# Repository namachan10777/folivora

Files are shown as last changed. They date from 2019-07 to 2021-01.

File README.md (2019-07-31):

# Folivora




Integrated ergonomics input device.

# Dependencies
 * KiCAD
 * OCaml
 * OpenSCAD

# License
MIT License

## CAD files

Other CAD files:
inventor/baseframe.ipt

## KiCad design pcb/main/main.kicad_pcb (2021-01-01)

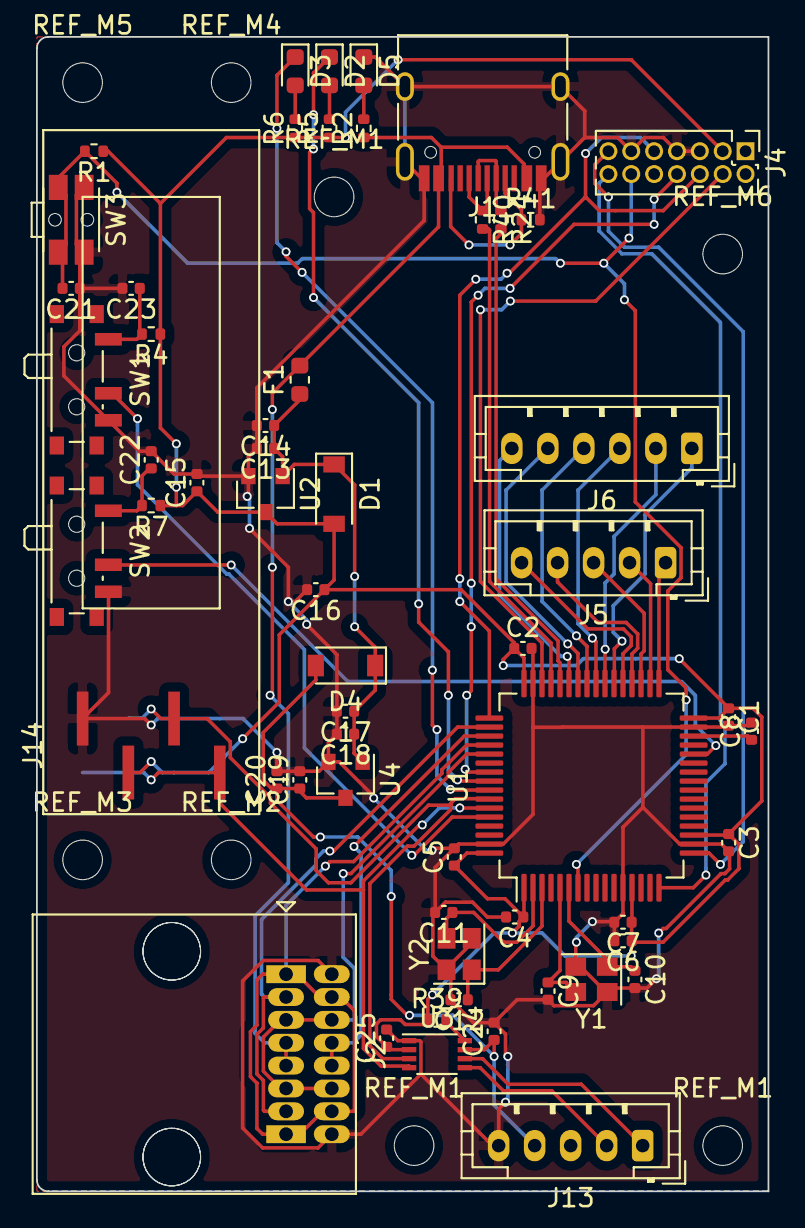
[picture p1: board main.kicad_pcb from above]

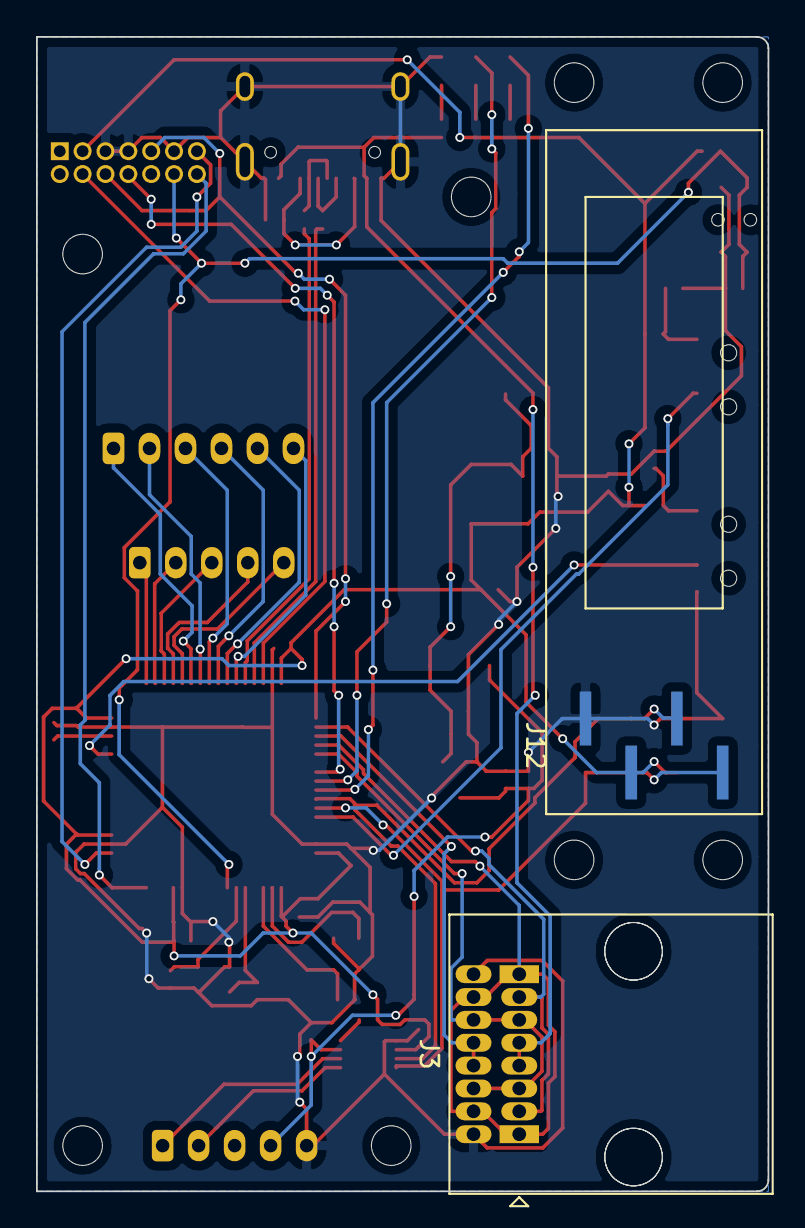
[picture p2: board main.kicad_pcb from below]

Board: 2 copper layers, 40.6 x 64.1 mm, 67 parts (2 on the bottom side), 50 nets.

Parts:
C1, C2, C3, C4, C5, C14, C15, C18, C19, C21, C22, C23, C24, C25: 0.1uF; C_0402_1005Metric
C6, C13, C16, C17, C20: 1uF; C_0402_1005Metric
C7: 10nF; C_0402_1005Metric
C8: 4.7uF; C_0402_1005Metric
C9, C10, C11, C12: C; C_0402_1005Metric
D1, D4: SBD; D_SOD-123
D2: Error; LED_0603_1608Metric
D3: Status; LED_0603_1608Metric
D5: LED_USB; LED_0603_1608Metric
F1: Polyfuse; Fuse_0603_1608Metric
J1: USB_C_Receptacle_USB2.0; USB_C_Receptacle_HRO_TYPE-C-31-M-12
J2, J3: RJ45; RJ45_rev
J4: STLink; PinHeader_2x07_P1.27mm_Vertical
J5: ROW; JST_PH_B5B-PH-K_1x05_P2.00mm_Vertical
J6: COL; JST_PH_B6B-PH-K_1x06_P2.00mm_Vertical
J12, J14: OLED
J13: trackball; JST_PH_B5B-PH-K_1x05_P2.00mm_Vertical
R1, R2, R4, R5, R6, R7, R39: R; R_0402_1005Metric
R24, R40: 10; R_0402_1005Metric
R41: 5.1k; R_0402_1005Metric
REF_M1, REF_M1#2, REF_M1#3, REF_M2, REF_M3, REF_M4, REF_M5, REF_M6: MountingHole_2.2mm_M2
SW1, SW2: SW_SPDT; SW_SPDT_PCM12
SW3: RESET; SW_SPST_EVQP7C
U1: STM32F401RETx; LQFP-64_10x10mm_P0.5mm
U2: NATLINEAR XT1861B332MR-G; SOT-23
U3: PCA9306DC1; VSSOP-8_2.3x2mm_P0.5mm
U4: HT7727; SOT-23
Y1: Crystal_8MHz; Crystal_SMD_2520-4Pin_2.5x2.0mm
Y2: Crystal_32.768MHz; Crystal_SMD_2520-4Pin_2.5x2.0mm

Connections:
+2V8: C19.1, C20.1, C24.1, D4.2, J13.4, U3.7, U4.3
+3V3: C1.1, C2.1, C3.1, C4.1, C5.1, C6.1, C7.1, C15.1, C16.1, C25.1, D1.2, J4.3, J12.2, J14.2, R1.1, R4.1, R5.1, R6.1, R7.1, R39.1, U1.1, U1.13, U1.19, U1.32, U1.48, U1.64, U2.3, U3.2
/BOOT0: SW1.2, U1.60
/BOOT1: SW2.2, U1.28
/COL1: J6.1, U1.38
/COL2: J6.2, U1.39
/COL3: J6.3, U1.40
/COL4: J6.4, U1.41
/COL5: J6.5, U1.42
/COL6: J6.6, U1.43
/D2+: J1.A7, J1.B7, R24.1
/D2-: J1.A6, J1.B6, R40.1
/D+: R24.2, U1.44
/D-: R40.2, U1.45
/LED_ERROR: D2.1, U1.56
/LED_STATUS: D3.1, U1.57
/MISO: J2.1, J2.2, J3.1, J3.2, U1.52
/MOSI: J2.3, J2.6, J3.3, J3.6, U1.53
/NRST: C21.2, J4.12, R1.2, SW3.2, U1.7
/ROW1: J5.1, U1.33
/ROW2: J5.2, U1.34
/ROW3: J5.3, U1.35
/ROW4: J5.4, U1.36
/ROW5: J5.5, U1.37
/RX: J4.13, U1.17
/SCL: J12.3, J14.3, U1.58, U3.3
/SCLK: J2.4, J3.4, U1.51
/SDA: J12.4, J14.4, U1.59, U3.4
/SS: J2.7, J3.7, U1.50
/SWCLK: J4.6, J4.9, U1.49
/SWDIO: J4.4, U1.46
/SWO: J4.8, U1.55
/TX: J4.14, U1.16
/XTAL1A: C9.1, U1.5, Y1.3
/XTAL1B: C10.1, U1.6, Y1.1
/XTAL2A: C11.1, U1.2, Y2.3
/XTAL2B: C12.1, U1.3, Y2.1
GND: C1.2, C2.2, C3.2, C4.2, C5.2, C6.2, C7.2, C8.2, C9.2, C10.2, C11.2, C12.2, C13.2, C14.2, C15.2, C16.2, C17.2, C18.2, C19.2, C20.2, C21.1, C22.2, C23.2, C24.2, C25.2, D5.1, J1.A1, J1.A12, J1.B1, J1.B12, J1.S1, J2.8, J3.8, J4.5, J4.7, J4.11, J12.1, J13.5, J14.1, R41.2, SW1.3, SW2.3, SW3.1, U1.12, U1.18, U1.31, U1.47, U1.63, U2.2, U3.1, U4.2, Y1.2, Y1.4, Y2.2, Y2.4
unnamed: C8.1, U1.30
unnamed: C13.1, C14.1, C17.1, C18.1, D1.1, D4.1, F1.1, U2.1, U4.1
unnamed: C22.1, R7.2, SW2.1
unnamed: C23.1, R4.2, SW1.1
unnamed: D2.2, R5.2
unnamed: D3.2, R6.2
unnamed: D5.2, R2.2
unnamed: J1.A5, J1.B5, R41.1
unnamed: J13.1, U3.6
unnamed: J13.2, U3.5
unnamed: R39.2, U3.8
VBUS: F1.2, J1.A4, J1.A9, J1.B4, J1.B9, J2.5, J3.5, R2.1

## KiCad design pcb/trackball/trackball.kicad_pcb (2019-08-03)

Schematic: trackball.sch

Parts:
C1, C3, C4, C5: 0.1uF; C_0603_1608Metric
J1: 5V; TestPoint_THTPad_D1.0mm_Drill0.5mm
J2: UP; TestPoint_THTPad_D1.0mm_Drill0.5mm
J3: R; TestPoint_THTPad_D1.0mm_Drill0.5mm
J4: D; TestPoint_THTPad_D1.0mm_Drill0.5mm
J5: L; TestPoint_THTPad_D1.0mm_Drill0.5mm
J7: GND; TestPoint_THTPad_D1.0mm_Drill0.5mm
R6, R7, R8, R9: 10k; R_0603_1608Metric
U1, U2, U3, U4: AN48841B; SMINI_5DE

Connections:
+5V: C1.1, C3.1, C4.1, C5.1, J1.1, R6.1, R7.1, R8.1, R9.1, U1.4 (Vcc), U2.4 (Vcc), U3.4 (Vcc), U4.4 (Vcc)
/DOWN: J4.1, R8.2, U3.5 (OUT)
/LEFT: J5.1, R9.2, U4.5 (OUT)
/RIGHT: J3.1, R7.2, U2.5 (OUT)
/UP: J2.1, R6.2, U1.5 (OUT)
GND: C1.2, C3.2, C4.2, C5.2, J7.1, U1.2 (GND), U2.2 (GND), U3.2 (GND), U4.2 (GND)

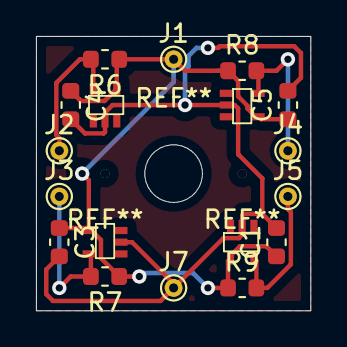
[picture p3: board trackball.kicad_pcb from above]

Board: 2 copper layers, 15.2 x 15.2 mm, 18 parts (0 on the bottom side), 6 nets.

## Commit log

2018-06-03 add mechanical design
    [Part6.ipt, ThumbPlate.ipt, baseframe.ipt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]
2018-07-06 update mechanical design
    [ball.ipt, ballcover.ipt, bearing.ipt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]
2018-07-20 設計の整理
    [Part6.ipt, ThumbPlate.ipt, ball.ipt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]
2018-07-21 左手側を追加
    [baseframe_left.ipt, folivora.iam, keyplate2.ipt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]
2018-07-21 どうにかしてセンサー設置空間を確保
    妥協と諦め
    [folivora.iam, trackball-cover.ipt, trackball_l.ipt]
2018-07-22 インターフェース設置用の穴を開けた
    [folivora.iam, palmrest-plate.ipt]
2018-07-22 add optsensor pcb
    [optsensor.kicad_pcb, optsensor.sch, trackball-base.dxf]
2018-07-27 左右対称なデザイン
    [baseframe_left.ipt, bearingcover.ipt, folivora.iam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]
2018-07-27 add drawings
    [baseframe.dxf, bearingcover.dxf, keyL.dxf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]
2018-07-28 add part of catting pattern
    [baseframe.dxf, bearingcover.dxf, keyL.dxf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]
2018-07-28 improve palmrest
    [folivora.iam, palmrest-plate.ipt, palmrest.ipt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]
2018-07-29 extend key
    [folivora.iam, keyL_extended.ipt, keyplate2.ipt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]
2018-07-29 down palmrest
    [folivora.iam, palmrest.ipt, palmrest_left.ipt]
2018-07-30 secure space for main pcb
    [main.kicad_pcb, palmrest-plate.dxf, palmrest-plate.ipt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]
2018-07-30 palmrestとキーの間に空間を設ける
    [baseframe_left.ipt, folivora.iam, palmrest.ipt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]
2018-08-10 revision design
    生産性の向上
    [baseframe_left.ipt, folivora.iam, keyL.ipt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]
2018-09-18 add main schematic
    [main.sch]
2018-09-18 fix directory structure
    [main.kicad_pcb, main.sch]
2018-09-18 remove regacy files
    [optsensor.kicad_pcb, optsensor.sch]
2018-09-18 determine circuit constant
    [main.sch]
2018-09-18 add XH6 to connect trackball
    [main.sch]
2018-09-18 impl main pcb
    [main.kicad_pcb, main.sch]
2018-09-22 fix main pcb
    [main.kicad_pcb, main.sch]
2018-09-22 update optsensor schematic
    [optsensor.sch]
2018-10-31 3d: add base
    [top.scad]
2018-11-01 add trackball anhorage
    [top.scad]
2018-11-04 improve naming of 3d/top.scad
    [top.scad]
2018-11-04 add bearing_cover
    [bearing_cover.scad]
2018-11-04 add ball_cover
    [ball_const.scad, ball_cover.scad, bearing_cover.scad]
2018-11-05 add screw hole to ball cover
    [ball_cover.scad]
2018-11-05 add bearing_base.scad
    [ball_const.scad, ball_cover.scad, bearing_base.scad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]
2018-11-05 fix warning of top.scad
    [top.scad]
2018-11-05 fix inside out
    [top.scad]
2018-11-05 add bearing_base to top.scad
    [bearing_base.scad, top.scad]
2018-11-05 add anchorage to trackball bridge
    [top.scad]
2018-11-10 fix trackball design
    [ball_const.scad, ball_cover.scad, bearing_base.scad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]
2018-11-22 reduce bearing module size
    [ball_const.scad, ball_cover.scad, bearing_base.scad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]
2018-11-30 Hello clojure!
    [ball_const.scad, ball_cover.scad, bearing_base.scad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]
2018-12-08 impl joint
2019-01-13 impl padding for key joint
2019-01-30 impl joint padding
2019-02-09 3d: add joint sidewall
2019-02-16 mechanical design
    [col4.kicad_pcb, col4.sch, main.kicad_pcb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]
2019-02-20 add bearing_hole
2019-02-20 impl bearing_holes
2019-02-20 refactor track.ml
2019-02-21 fix Track.foundation
2019-02-23 main pcb: fill
    [main.kicad_pcb]
2019-02-23 add pcb opt
    [opt.kicad_pcb, opt.sch]
2019-02-23 add bearinghdge hollowing
2019-02-23 add screw_holes
2019-02-23 impl bearing_cover
2019-02-26 下から球が抜けるように
2019-02-28 Track: for FDM
2019-03-04 最初の方
2019-03-09 add zip-pcb-files.sh
2019-03-10 for Φ2.5 axis
2019-03-10 actually, I use Φ3
2019-03-11 hollow for screw head
2019-03-11 for Φ12.5 sphere
2019-03-12 fix bearing cover tilt
2019-03-13 revise main pcb
    [main.kicad_pcb, main.sch]
2019-03-17 revise row
    [col4.kicad_pcb, col4.sch, row.kicad_pcb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]
2019-03-18 complete sch
    [main.sch]
2019-03-18 arrange parts
    [main.kicad_pcb]
2019-03-18 use STM32F103C8T6 directly
    [main.kicad_pcb, main.sch]
2019-03-19 keyboard pcb
    [main.kicad_pcb, main.sch]
2019-03-19 add main-trackball
    [main.kicad_pcb, main.sch]
2019-03-20 fix design
    [main.kicad_pcb, main.sch, row.kicad_pcb]
2019-03-22 for Φ25
2019-03-22 slanting cut
2019-03-27 temporarily assembled wall
2019-03-28 screw holes for keymodule
2019-03-29 X axis values are determined by inch
    This is so humiliating...
2019-03-29 infinit probability
    [breakout.kicad_pcb, breakout.sch, row.kicad_pcb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]
2019-04-08 rename track -> thumb
2019-04-12 joint thumb and pad
2019-04-14 add wire passage
2019-04-16 impl plate
2019-07-22 add blackberry trackball parts
    [trackball.kicad_pcb, trackball.sch]
2019-07-23 complete trackball breakout
    [trackball.kicad_pcb, trackball.sch]
2019-07-27 trackball breakout
    [trackball.kicad_pcb, trackball.sch]
2019-07-29 add screw_mount
2019-07-30 rm pcbs
    [breakout.kicad_pcb, breakout.sch, main.kicad_pcb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]
2019-07-30 add plate
2019-07-31 improve circuit board mount point
2019-07-31 manual scaling circuit board.
2019-08-03 change BlackPill footprint non-reversible
2019-08-03 optimized electrical board space
2019-08-03 complete pcb design
    [main.kicad_pcb, main.sch]
2019-08-03 resize main pcb
    [main.kicad_pcb]
2019-08-03 hollow cable tunnel
2019-08-03 production pcb
    [main.kicad_pcb, trackball.kicad_pcb]
2019-08-03 add Micro_hole footprint
2020-10-10 full joint
2020-10-29 joint top
2020-11-01 fix pcb
    [main.kicad_pcb, main.sch]
2020-11-01 pcb inserted
2020-11-01 insert patch
2020-11-01 add screw point
2020-11-03 add screws
2020-11-06 screw bottom top_cut
2020-11-06 pcb update
    [main.kicad_pcb, main.sch]
2020-11-26 redesign pcb
    [main.kicad_pcb, main.sch]
2020-11-27 fix RJ45 placing
    [main.kicad_pcb]
2020-11-29 fix connector
    [main.kicad_pcb, main.sch]
2021-01-22 adjust screw position
2021-01-23 fix screw position
2021-01-23 adjust screw positions
2021-02-04 fix screw
2021-02-07 人差し指遠かった
2021-02-07 adjust screw
2021-02-07 fix screws
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
